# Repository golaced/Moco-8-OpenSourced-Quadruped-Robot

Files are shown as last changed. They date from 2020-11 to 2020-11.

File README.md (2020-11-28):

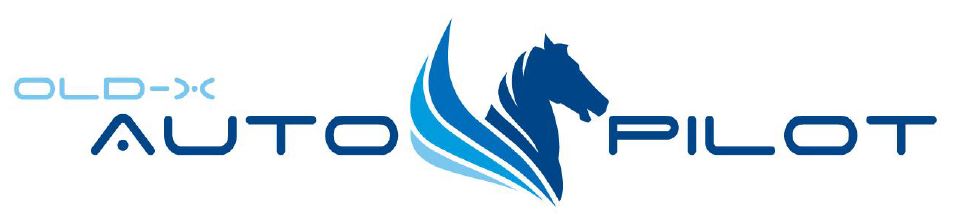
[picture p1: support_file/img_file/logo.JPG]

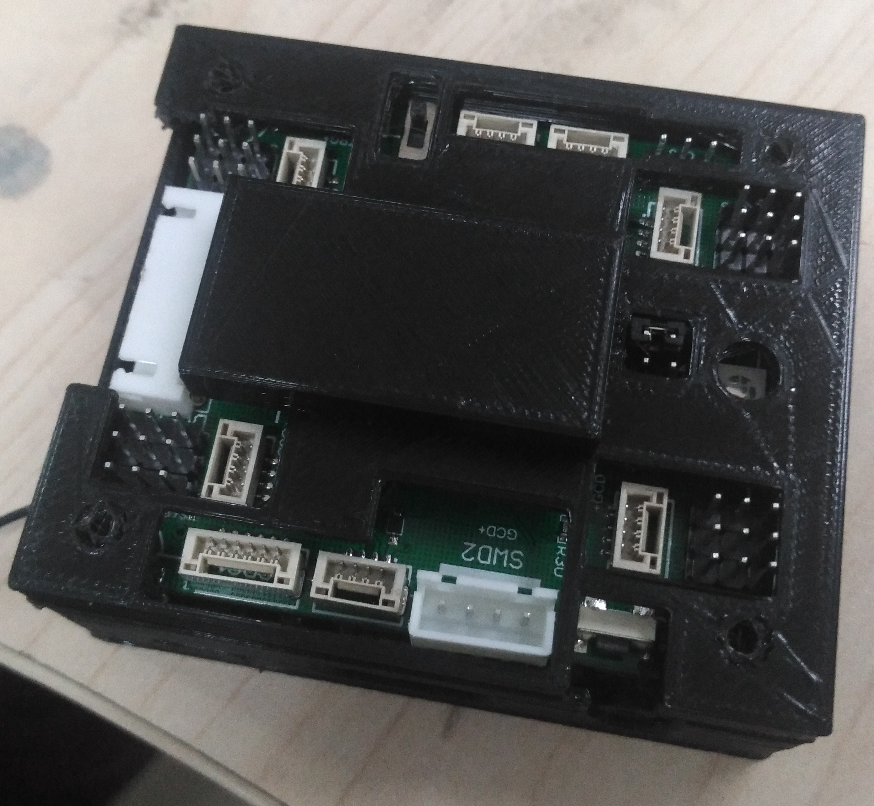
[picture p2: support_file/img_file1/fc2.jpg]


**-项目全开源-**<br>
Moco8项目目前已经全开源，开源PCB加工文件与官方机架，开源VMC原始1.3.5库的完整程序与遥控器程序，同样可以直接从淘宝官网或邮件预定整机（供货周期半个月）<br>

**English Version**：https://github.com/golaced/OLDX-FC_QUADRUPED_QUADROTOR/tree/golaced-patch-1-en <br>

全开源8自由度四足机器人  欢迎Star（原始资料：https://github.com/golaced/OLDX-FC_QUADRUPED_QUADROTOR）<br>
  ____OLDX-MocoMoco四足机器人（OLDX-MocoMoco Quadruped）是目前国内首个真正意义上的开源足式机器人二次开发平台，团队已经开发了一套完整的免费开源
  项目OLDX-FC，随着近年来波士顿动力公司不断推出的足式机器人引起了国内外许多爱好者的关注，也出现了许多电子发烧友自己开发的足式机器人，但
  不同于四轴飞行器仅采用无刷电机和机架就能进行开发，而足式机器人本身结构复杂特别是伺服驱动部分可以独立作为一个学科进行研究，因此造成了
  虽然有许多不错的足式机器人项目但是由于项目成本或者编程语言不为国内环境所熟悉的原因而阻碍了它们的推广或开源。团队4年前就开始研发的六
  足机器人具有丰富的机器人，通过将其与所开发的飞控项目二次结合推出了MocoMoco四足机器人开发平台，囊括机器人结构、步态算法和SLAM无人驾驶
  等多个足式机器人核心技术内容。项目遵循GPL协议，能对DEMO内相关源码进行修改和二次开发。<br><br>

**相关资料** <br>
组装资料教程：https://github.com/golaced/OLDX-FC_QUADRUPED_QUADROTOR<br>
机器人测试视频更新地址：https://www.bilibili.com/video/av46405055 <br>
为方便程序单独下载目前各版本固件从这下载：https://github.com/golaced/MocoMoco_Software<br>
机器人校准视频教程：https://www.bilibili.com/video/av51603154<br>
树莓派镜像和图像程序：https://github.com/golaced/OLDX_VISUAL_FOR_PI<br>
<br>

官方机架taobao链接：https://item.taobao.com/item.htm?spm=a1z10.1-c.w4004-15110596499.22.6b86242c3mvjW9&id=589551490320
<br>
**-如果该项目对您有帮助请 Star 我们的项目-**<br>
**-如果您愿意分享对该项目的优化和改进请联系golaced@163.com或加入我们的QQ群567423074，加速开源项目的进度-**<br>

# 捐赠与项目后续开发计划
____团队计划后期推出5kg~10kg级的足式机器人开发底盘，支持RPlidar激光雷达导航进行SLAM算法验证，能以相同的价格替代目前市面上同类的四轮小车平台如Autolabor等。
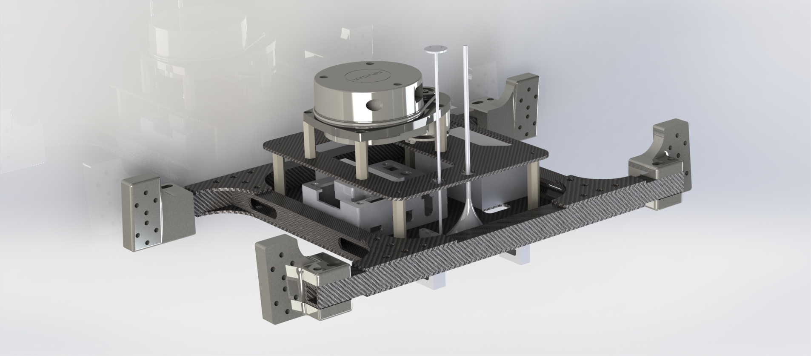
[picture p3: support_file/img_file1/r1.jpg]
 
____如果您觉得该项目对您有帮助，也为了更好的项目推进和软硬件更新，如果愿意请通过微信捐赠该项目！
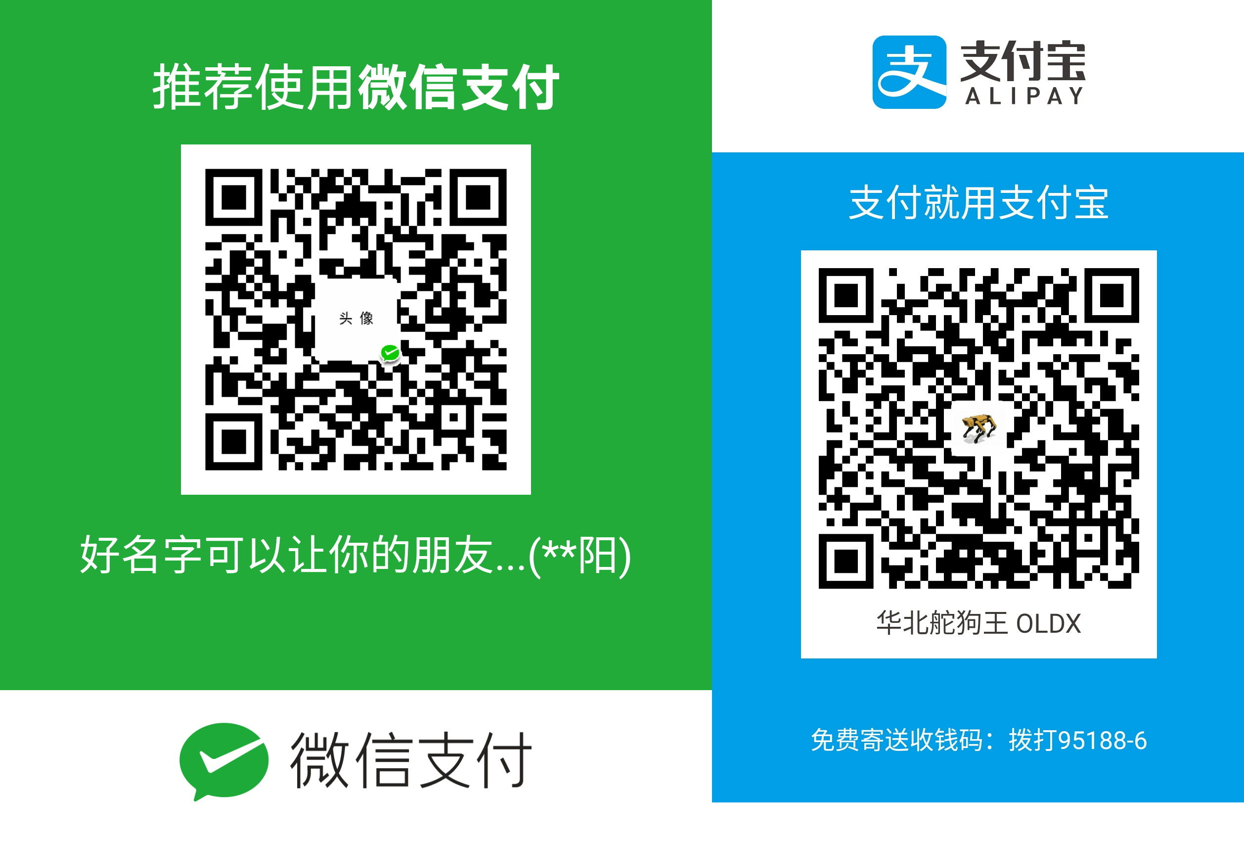
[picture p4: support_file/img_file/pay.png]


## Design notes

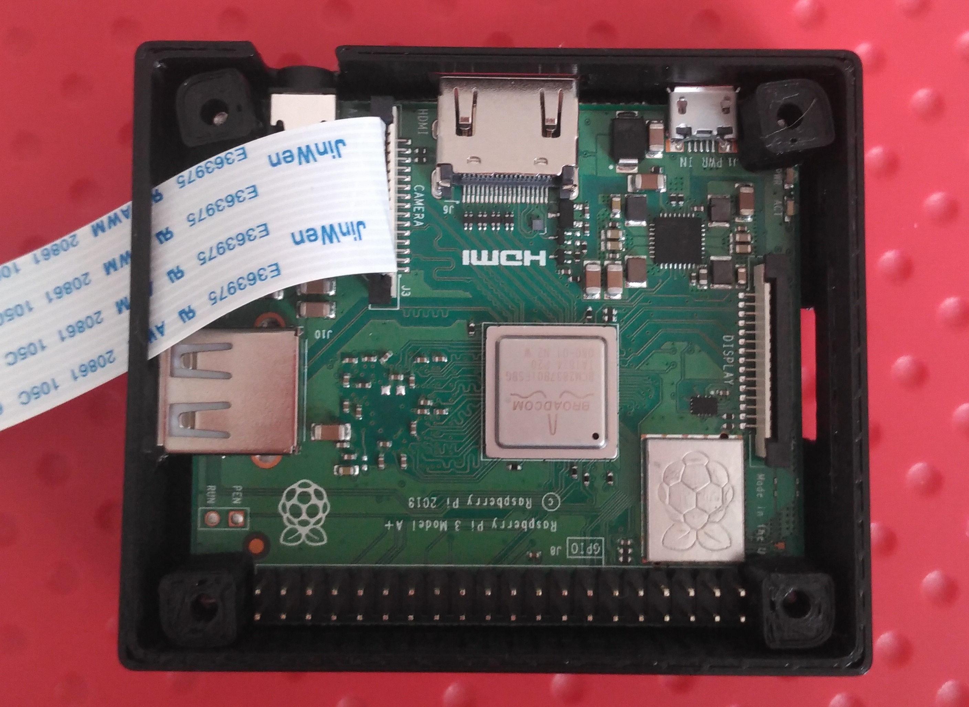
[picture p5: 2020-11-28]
support_file/img_file1/pi1.jpg

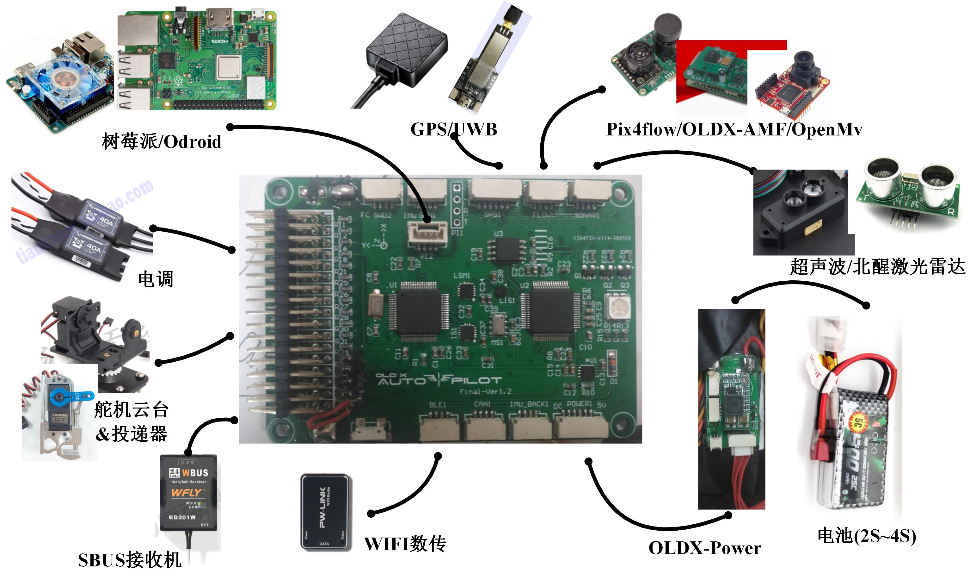
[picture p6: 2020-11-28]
support_file/img_file/line.jpg

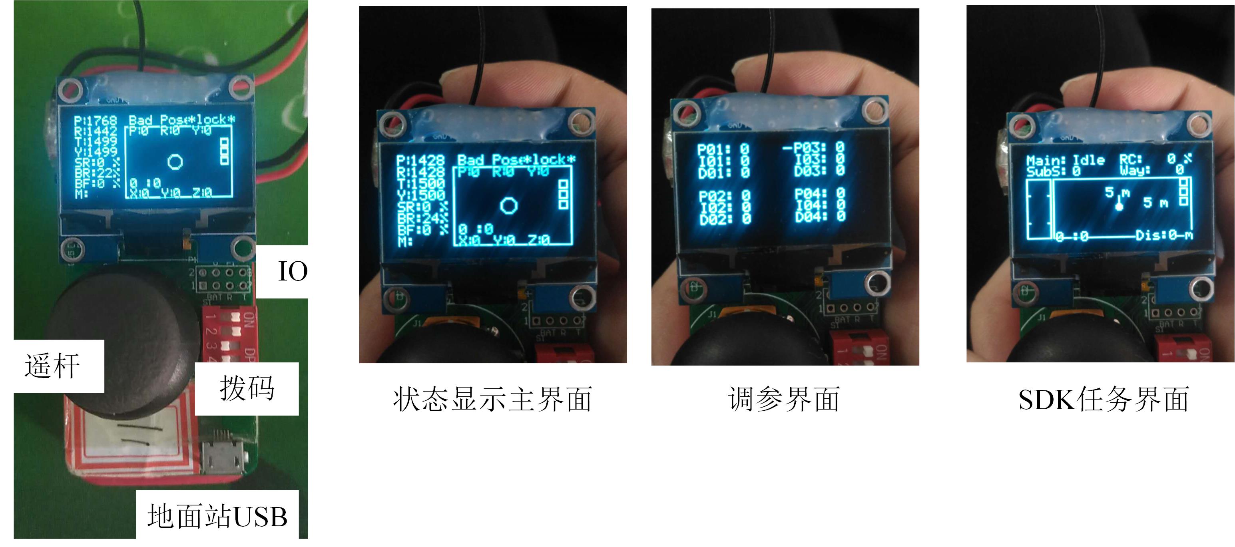
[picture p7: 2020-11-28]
support_file/img_file/remote.jpg

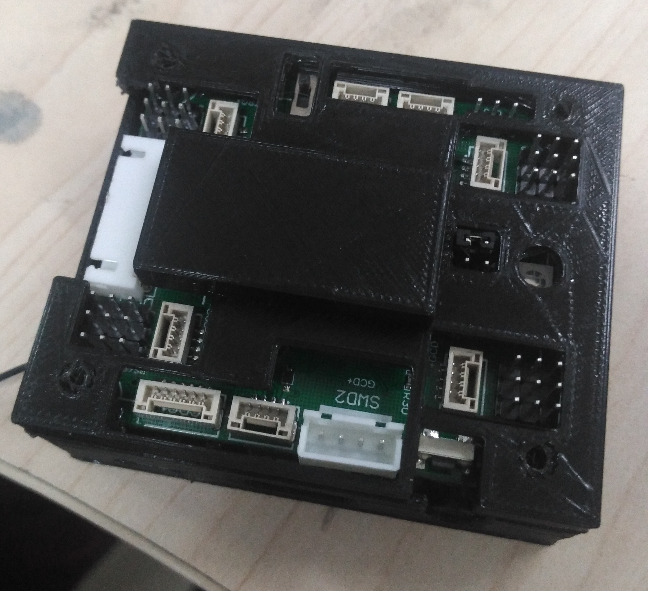
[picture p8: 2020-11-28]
support_file/img_file1/pi3.jpg

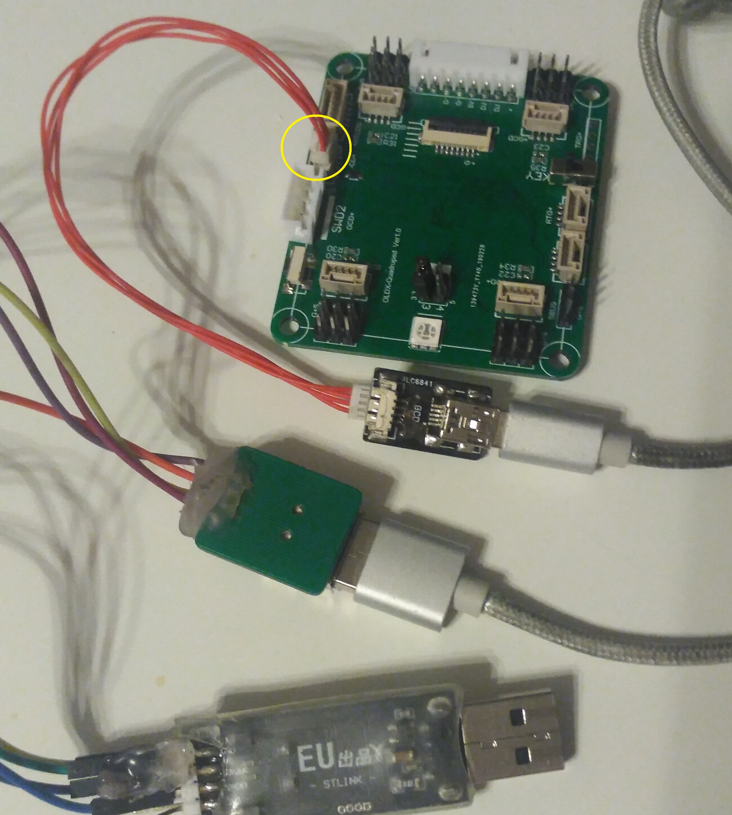
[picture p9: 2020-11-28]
support_file/img_file1/download.jpg

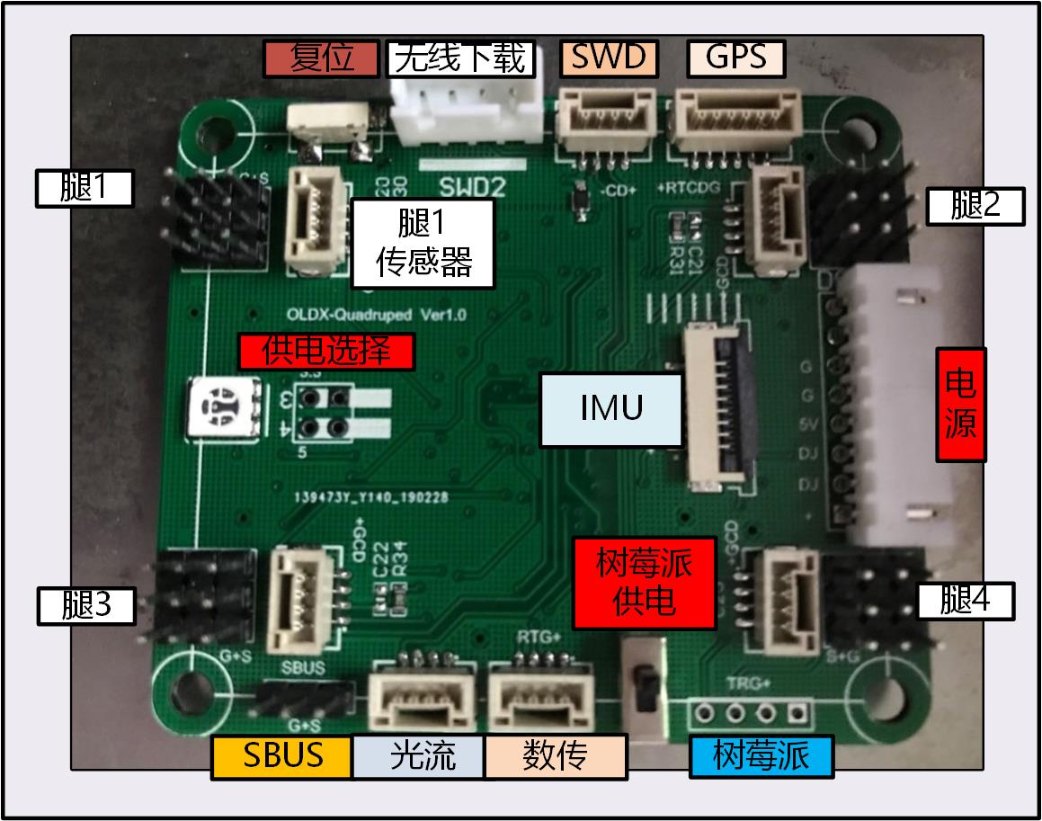
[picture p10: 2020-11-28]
support_file/img_file1/fc.jpg

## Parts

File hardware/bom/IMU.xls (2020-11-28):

Comment | Description | Designator | Footprint | LibRef | Quantity
0.1UF | Capacitor | C1 | C 0402 | CAP | 1
0.1UF | Capacitor | C2, C4, C6 | C0603 | CAP | 3
100nF | Capacitor | C3 | C0603 | CAP | 1
4.7uf | Capacitor | C5 | C0603 | CAP | 1
LIS3MDL | 磁力计 | LIS1 | LIS3MDL | LIS3MDL | 1 | 可选
LSM6DS33 | 加速度计 | LSM1 | LSM6DS33 | LSM6DS33 | 1
Header 8 | 8P 下接 抽屉 | MEMS1 | FH12-8S-1.0SH | Header 8 | 1 | 配1mm 8p软排线 异面 3 cm长
MS5611 | Sensor | MS1 | MS5611 | MS5611 | 1 | 可选

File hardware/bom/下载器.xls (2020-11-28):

Comment | Description | Designator | Footprint | Quantity
0.1UF | Capacitor | C1 | C0603 | 1
1N4148 | 二极管 | D1 | 1n4148-SOD123 | 1
10K | 0603 | R1, R2 | R0603 | 2
MicroUSB口 |  | ST_Link_1 | USB/SM0.8-6H5_M | 1
4P卧贴 | Header, 4-Pin | SWD1 | JST_GH_V4 | 1 | https://item.taobao.com/item.htm?spm=a1z09.2.0.0.MJL2ZN&id=528744124006&_u=o1klsj899edd

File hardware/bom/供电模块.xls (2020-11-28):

Comment | Description | Designator | Footprint | LibRef | Quantity
BAT54WS | 单肖特基二极管 | D1 | SOD-323 | BAT54 | 1
Header 8 | XH2.54 弯端子 | DC1 | HDR1X8 | Header 8 | 1 | 配8P双头线 | 6cm
DET402_1 | 蜂鸣器 | DET1 | BEEP | DET402_1 | 1
DCDC1 | 2.54排针 | DJ1, FC1 | DCDC1 | DCDC1 | 2
S8050 | 8050/BCW846/BCW847 | Q1, Q2 | SOT-23R | NPN | 2
1K | 0603 | R1, R4 | R0603 | Res2 | 2
10K | 0603 | R2 | R0603 | Res2 | 2
NC | 0603 | R3, R5 | R0805 | Res2 | 1
FC1 | 降压模块5V | 控制器供电 |  |  | 1 | https://item.taobao.com/item.htm?spm=a1z09.2.0.0.15212e8dszODOn&id=572382517694&_u=k1klsj89d0b4
DJ1 | 降压模块6V | 舵机供电 |  |  | 1 | https://item.taobao.com/item.htm?spm=a1z09.2.0.0.15212e8dszODOn&id=572382517694&_u=k1klsj89d0b4

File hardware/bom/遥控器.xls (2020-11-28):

Comment | Description | Designator | Footprint | Quantity
AS1364-BTDT-33 | 3.3稳压 | *U1 | TDFN-8 | 1
TP4059 | 充电芯片 | B1 | SOT23-6S | 1
1UF | 贴片电容 | C1, C3 | C0603 | 2
0.1UF | 贴片电容 | C2, C4, C5, C13, C14, C15, C16, C21, C47 | C0603 | 9
20PF | 贴片电容 | C6, C7 | C0603 | 2
10nf | 贴片电容 | C20, C23 | C0603 | 2
4.7uf | 贴片电容 | C22, C24 | C0603 | 2
22uF | 贴片电容 | C25 | C0603 | 1
10UF | 贴片电容 | C48 | C0603 | 1
BAT54WS | 单肖特基二极管 | D1 | SOD-323 | 1
IN4733 5.1V | 稳压二极管5.1V | D2 | 1n4148-SOD123 | 1
蜂鸣器 | 蜂鸣器 | DET1 | BEEP | 1 | https://item.taobao.com/item.htm?id=557399448031&ns=1&abbucket=8
方向摇杆 | 摇杆 | J1 | 摇杆2 | 1 | https://item.taobao.com/item.htm?id=531096275220&ns=1&abbucket=14 (https://item.taobao.com/item.htm?spm=a230r.1.14.99.30965b5bjNmqxk&id=531096275220&ns=1&abbucket=14)
DS0 | LED 蓝 | LED2 | LED_0603 | 1 | 遥杆需要配帽
MPU9250 | 传感器 | MPU1 | MPU_QFN24_0.4 | 1
Header 3 | 三段侧开关 | P2 | HDR1X3 | 1 | https://item.taobao.com/item.htm?id=526166466029
S8050 | 三极管 | Q1 | SOT-23R | 1
1K | 贴片电阻 | R1, R2, R10, R18, R19, R21, R52, R53 | R0603 | 8
1M | 贴片电阻 | R3 | R0603 | 1
10K | 贴片电阻 | R4, R5, R6, R7, R13, R14, R15, R16, R22 | R0603 | 9
10R | 贴片电阻 | R8, R9 | R0603 | 2
0R | 贴片电阻 | R11, R12 | R0603 | 2
4.7K | 贴片电阻 | R17, R20 | R0603 | 2
SW-DIP4 | 拨码开关 | S1 | DIP-8 | 1
SD | 自弹TF卡座 | SD_OLED1 | TF-MicroSD | 1
Header 4 | 卧贴侧端子 | SWD1 | JST_GH_V4 | 1 | 配2根4p双头线 | https://item.taobao.com/item.htm?spm=a1z09.2.0.0.51752e8dlo9hak&id=528691263571&_u=o1klsj894c50
STM32F103C8 | STM32F103c8 | U1 | LQFP48S | 1
USB-B(Mini) | USB | USB | Micro_USB | 1
8MHZ | 无源晶振 | X1 | PXCL | 1
NRF1 | NRF模组 | NRF1 | NRF | 1 | https://item.taobao.com/item.htm?spm=a1z09.2.0.0.65212e8dLKOq2l&id=45719116718&_u=31klsj89072b
OLED | OLED屏幕 | OLED | OLED | 1 | https://detail.tmall.com/item.htm?id=41844085048&spm=a1z09.2.0.0.51752e8dlo9hak&_u=o1klsj895f3e
供电端子(母) |  | https://item.taobao.com/item.htm?spm=a1z09.2.0.0.51752e8dlo9hak&id=39955787073&_u=o1klsj89d67d
G黑线

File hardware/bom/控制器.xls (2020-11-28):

Comment | Description | Designator | Footprint | Quantity
AS1364-BTDT-33 | 降压模块 | *U1 | TDFN-8 | 1
0.1UF | 贴片电容 | C1, C9, C13, C15, C16, C17, C18 | C 0402 | 7
1UF | 贴片电容 | C2 | C 0402 | 1
2.2UF | 贴片电容 | C3, C4 | C0603 | 2
10NF | 贴片电容 | C5 | C 0402 | 1
20PF | 贴片电容 | C6, C7 | C 0402 | 2
4.7uf | 贴片电容 | C10, C12 | C0603 | 2
10nf | 贴片电容 | C11 | C0603 | 1
100uF | 贴片电容 | C19 | C0603 | 1
NC | 贴片电容 | C20, C21, C22, C23 | C0603 | 4
R0 | 单肖特基二极管 | D4 | SOD-323 | 1
SWD2 | 2.54 XH端子 4P 立贴 | SWD2 | SWD2 | 1
Header 8 | 2.54 XH端子 卧贴 | DC | HDR1X8 | 1
Header 4 | GH1.25端子 立贴 | FLOW, IIC1, IIC2, IIC3, IIC4, RADIO, SWD1 | JST_GH_V4 | 7
Header 6 | GH1.25端子 立贴 | GPS1 | JST_GH_V6 | 1 | https://item.taobao.com/item.htm?spm=a1z09.2.0.0.70a52e8drw8IxJ&id=528744124006&_u=l1klsj89de6f
MSK-12D19 | 立三档开关 | KEY | HDR1X3 | 1
5050 RGB | 三色LED | LEDRGB1 | 5050RGB | 1
Header 8 | 1mm软线 翻盖 下接 | MEMS | FH12-8S-1.0SH | 1 | 配30mm异面排线 | 配天线https://item.taobao.com/item.htm?spm=a1z09.2.0.0.16032e8daiTpOp&id=524223974321&_u=k1klsj898d21
NRF模组 | NRF模组 | NRF1 | NRF | 1 | https://item.taobao.com/item.htm?spm=a1z09.2.0.0.65212e8dLKOq2l&id=45719116718&_u=31klsj89072b
Header 3 | 2.54排针 | P1, P2, P3, P5, P6, P7, P8, P9, P10, P11, P12, P13, P14 | HDR1X3 | 13 | 向下焊接
Header 4 | 2.54排针母座 | PI1 | HDR1X4 | 1
S8050 | 8050/BCW846/BCW847 | Q2, Q3, Q4, Q5 | SOT-23R | 4
10K | 贴片电阻 | R1, R4, R5, R6, R33 | R 0402 | 5
1K | 贴片电阻 | R7, R11, R12, R30, R31, R34, R35 | R0603 | 7
560R | 贴片电阻 | R8, R10, R13, R17, R18, R19, R25, R26, R27, R28, R29, R32, R36 | R 0402 | 13
10K | 贴片电阻 | R9 | R0603 | 1
100R | 贴片电阻 | R14, R15, R16 | R 0402 | 3
1K | 贴片电阻 | R20, R21, R22 | R 0402 | 3
Header 2X2 | 2.54排针 | SEL | HDR2X2 | 1 | 配跳线帽
SW-PB1 | 侧贴按键 | SW1 | KEY_SAD | 1
STM32F405RGT6 | 单片机 | U1 | LQFP64_M | 1
W25X16 | W25X16;SST25VF016;MX25L1605 | U2 | W25Q32FVZPIG | 1
8MHZ | 无源晶振 | X1 | PXCL | 1
 | 图中LED焊接错误 缺口应在箭头处

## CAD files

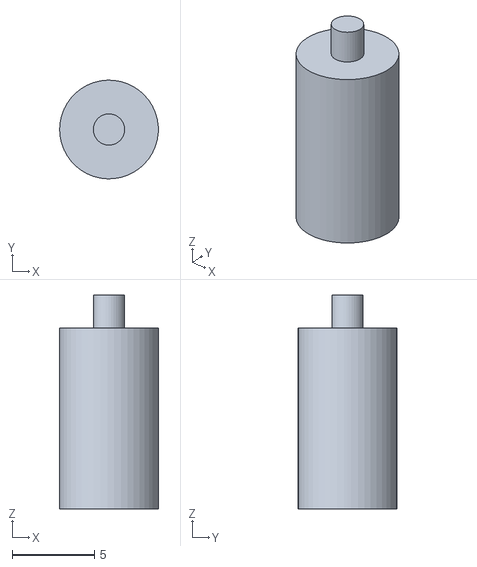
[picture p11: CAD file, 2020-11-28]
hardware/3D print/树莓派支撑_新.STL
6.00 x 6.00 x 13.0

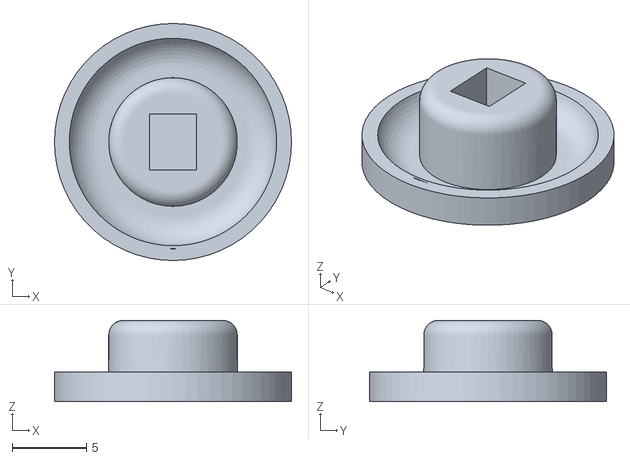
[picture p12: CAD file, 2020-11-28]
quadruped/3D打印测试机架/足底带传感器1.STL
16.0 x 16.0 x 5.50

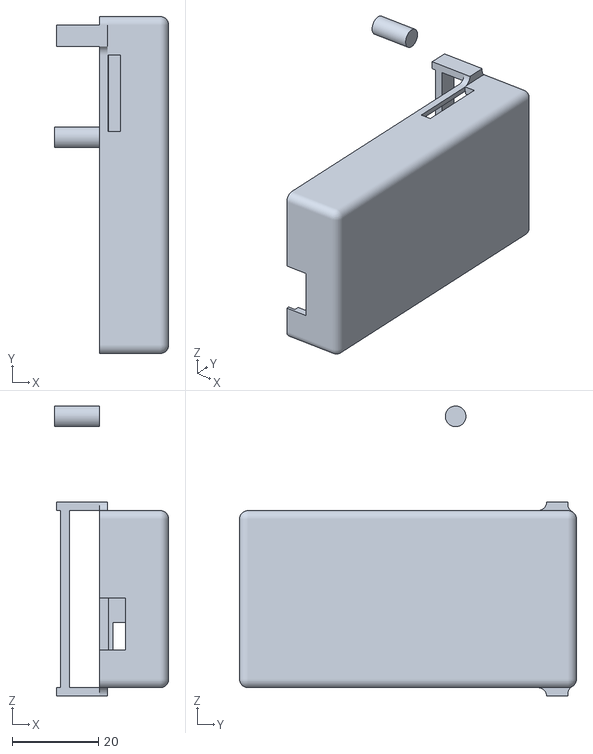
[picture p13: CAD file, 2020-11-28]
hardware/3D print/遥控器外壳.STL
26.5 x 78.0 x 67.1

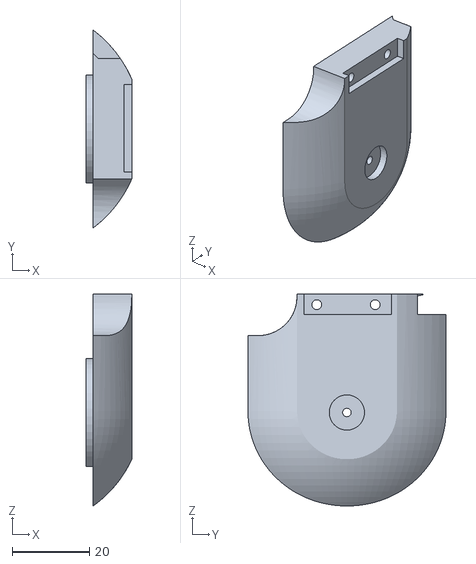
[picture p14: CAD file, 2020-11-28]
quadruped/3D打印测试机架/两轴云台2.STL
11.8 x 51.2 x 54.8

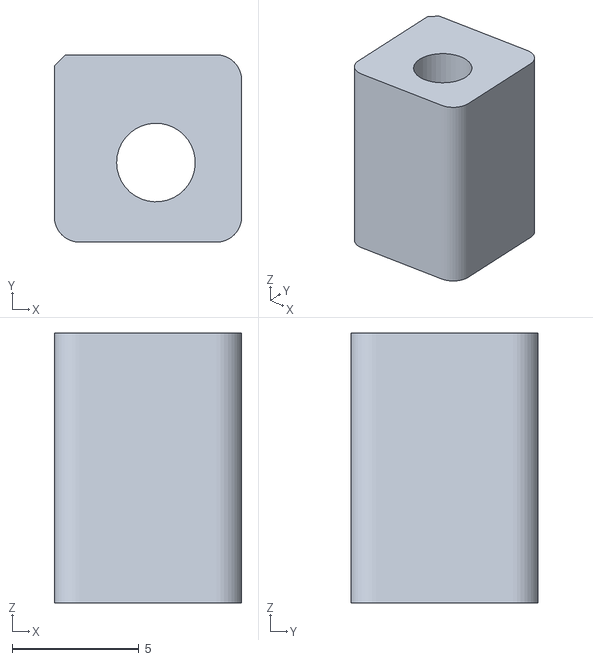
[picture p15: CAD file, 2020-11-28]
hardware/3D print/树莓派支撑.STL
7.39 x 7.39 x 10.6

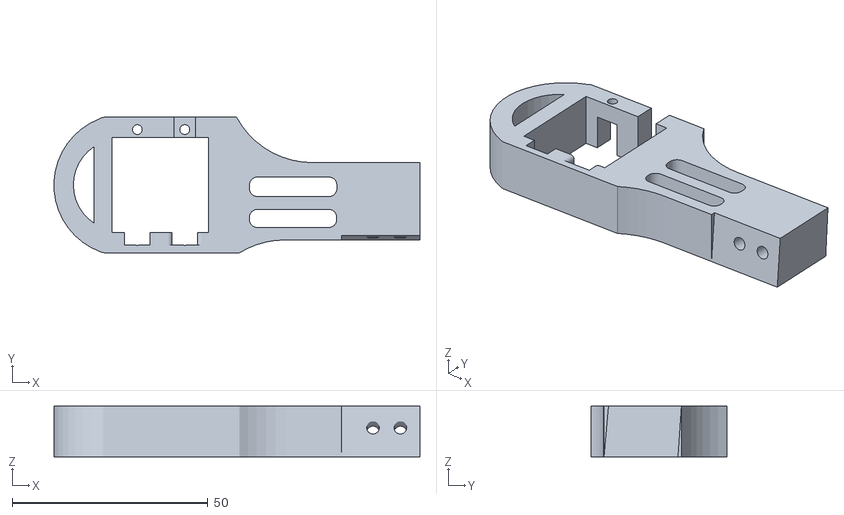
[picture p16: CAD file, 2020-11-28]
quadruped/3D打印测试机架/机臂.STL
93.4 x 34.6 x 13.0

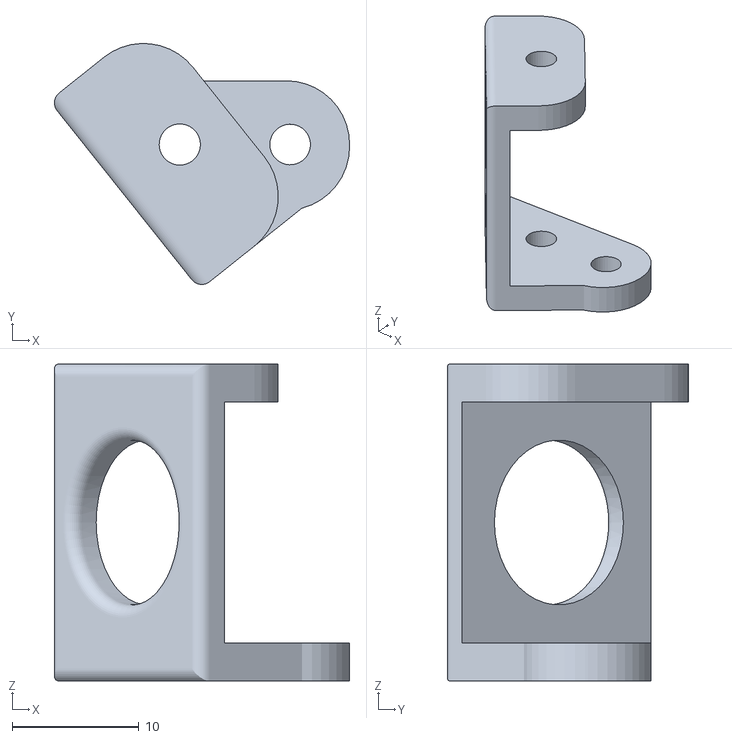
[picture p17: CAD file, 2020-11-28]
quadruped/3D打印测试机架/足底带传感器2(需镜像打印).STL
23.3 x 19.0 x 25.0

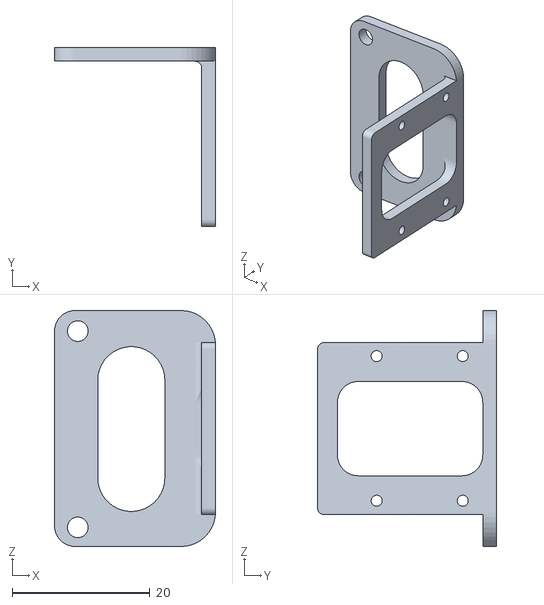
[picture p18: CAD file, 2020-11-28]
quadruped/3D打印测试机架/相机支撑1.STL
23.4 x 26.0 x 34.3

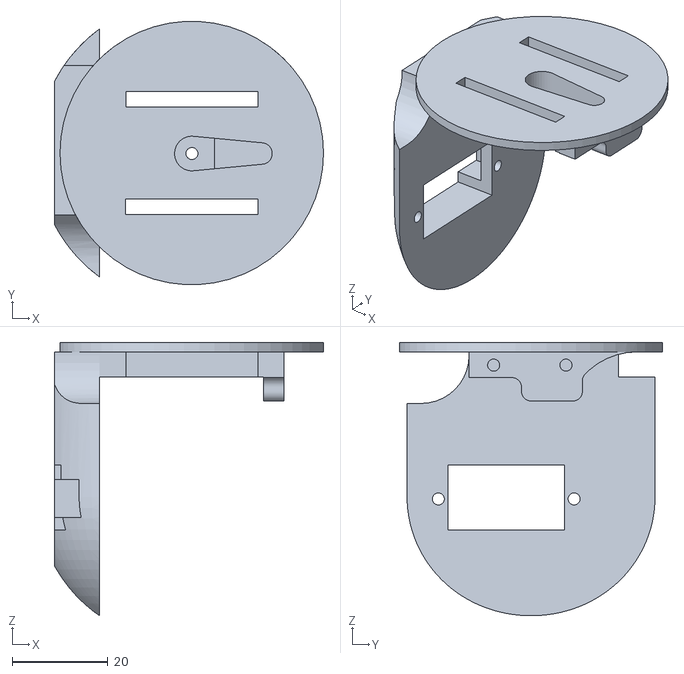
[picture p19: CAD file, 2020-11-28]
quadruped/3D打印测试机架/两轴云台3.STL
56.1 x 54.8 x 57.0

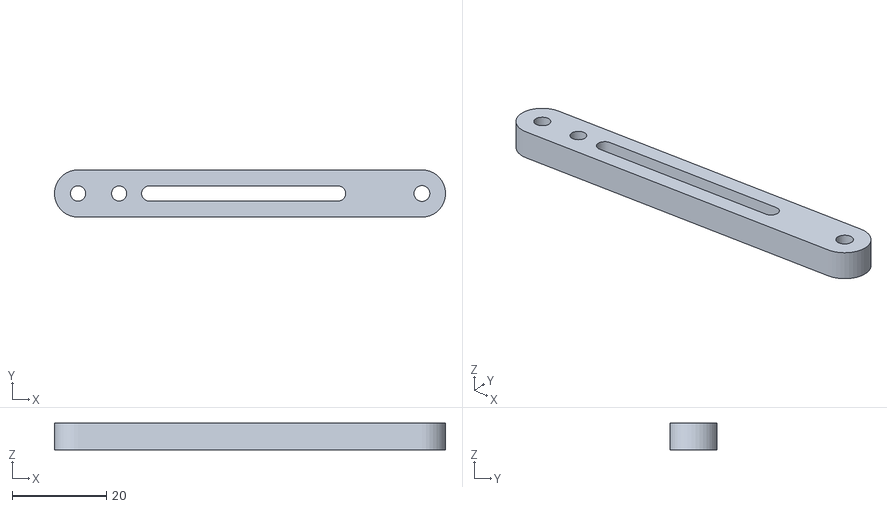
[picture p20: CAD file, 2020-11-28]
quadruped/3D打印测试机架/腿关节.STL
83.0 x 10.1 x 5.70

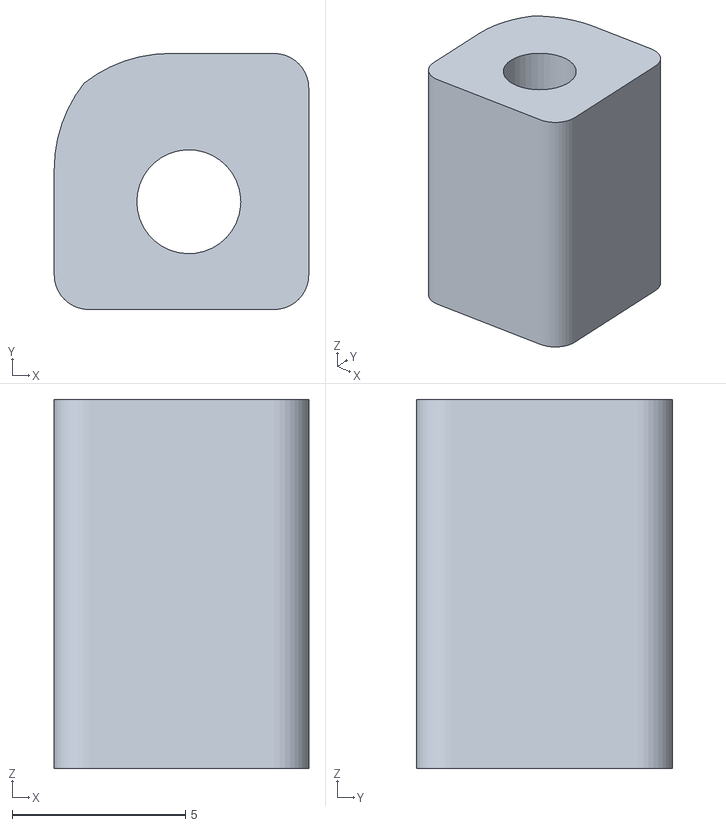
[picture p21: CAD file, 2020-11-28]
quadruped/3D打印测试机架/控制器外壳支撑.STL
7.35 x 7.39 x 10.6

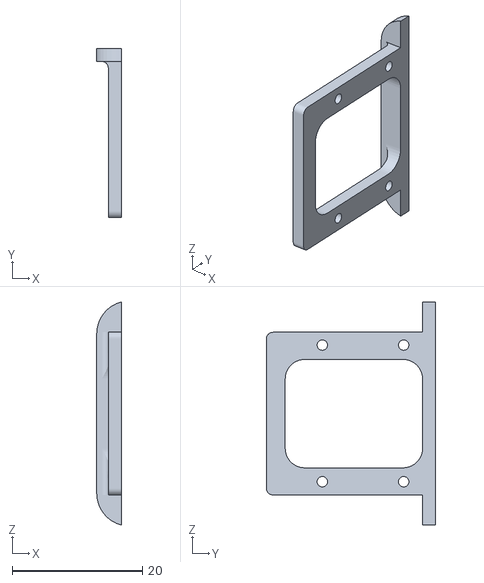
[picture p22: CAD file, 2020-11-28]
quadruped/3D打印测试机架/两轴云台5.STL
3.78 x 26.0 x 34.3

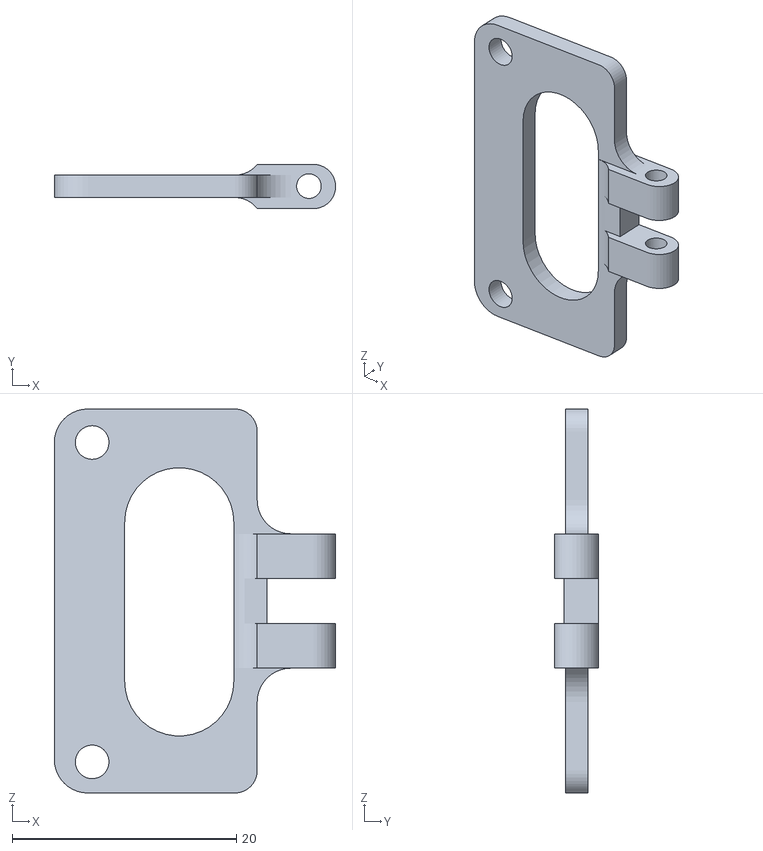
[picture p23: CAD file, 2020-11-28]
quadruped/3D打印测试机架/相机支撑可调 2.STL
25.1 x 3.96 x 34.3

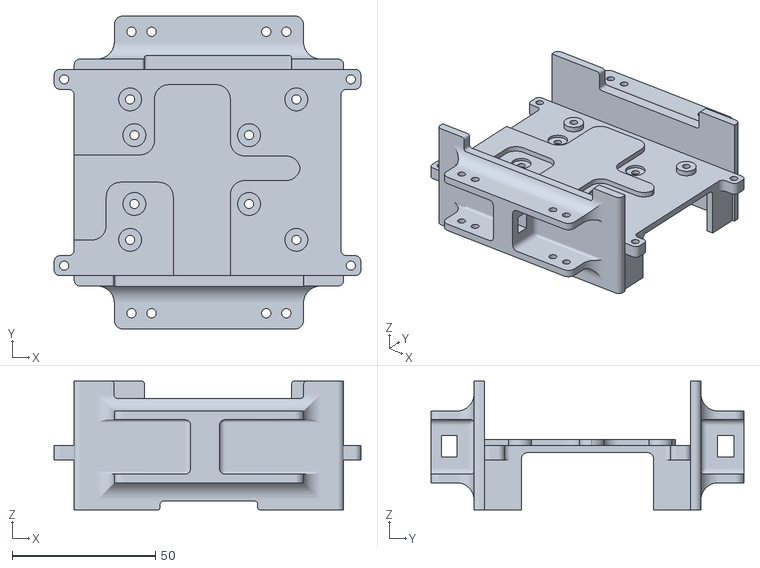
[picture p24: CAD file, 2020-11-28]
quadruped/3D打印测试机架/中心体.STL
107.0 x 109.2 x 45.0

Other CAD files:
quadruped/3D打印测试机架/树莓派相机支撑.STL
quadruped/3D打印测试机架/两轴云台1.STL
quadruped/3D打印测试机架/相机支撑可调1.STL
quadruped/3D打印测试机架/两轴云台4.STL

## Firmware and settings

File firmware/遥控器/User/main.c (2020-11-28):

#include "head.h"
#include "table.h"
#include "spi.h"
#include "nrf.h"
#include "adc.h"
#include "key.h"
#include "mpu9250.h"
#include "FLASH.h"
#include "imu.h"
#include "mymath.h"
#include "math.h"
#include "rc_mine.h"
#include "beep.h"
#include "gui_basic.h"
#include "hw_config.h"
#include "data_transfer.h"
#define USE_AS_MONITER 0
MODULE module;
u8 CHANNAL=44;
float time_fly[5]={0,0,0,0,2.68};
int moniter_sel=0;
int sub_sel[3]={0};
int ts[4];
void OLED_TASK(float dt)//状态界面0
{
	 static int cx,cy;
	 char temp[10][20]={'\0'};
   //GUI_RectangleFill(42,1,123,55,0);
   GUI_RectangleFill(1,1,123,55,0);
   GUI_Rectangle(42,1,123,55,1);
 
   if(plane.module.gps)
		GUI_RectangleFill(115,40,120,45,1);
   else
		GUI_Rectangle(115,40,120,45,1); 
	 
	  if(plane.module.flow)
		GUI_RectangleFill(115,38,120,33,1);
   else
		GUI_Rectangle(115,38,120,33,1); 
	 
	  if(plane.module.vision)
		GUI_RectangleFill(115,31,120,26,1);
   else
		GUI_Rectangle(115,31,120,26,1); 
   #if USE_AS_MONITER
   if(DEBUG[6]!=0&&DEBUG[7]!=0){
   cx=LIMIT(80+(DEBUG[6]-120)*0.35,42+3,123-3);
   cy=LIMIT(28+(DEBUG[7]-160)*0.168,1+3,55-3);
	 GUI_CircleFill(cx,cy,2,1);	 
	 }
	 else
	 GUI_CircleFill(cx,cy,2,0);	 
   #else
   cx=LIMIT(80+(Rc_Get.ROL-1500)*0.1,42+3,123-3);
   cy=LIMIT(28+(Rc_Get.PIT-1500)*0.1,1+3,55-3);
	 GUI_CircleFill(cx,cy,3,1);
   #endif
   GUI_Circle(80,28,5,1);   
   //
   OLED_Refresh_Gram(); 
   delay_us(100);
   //
   OLED_P6x8Str(3,0,"P:");
   my_itoa(Rc_Get.PIT,temp[0]);
	 OLED_P6x8Str(4*3,0,temp[0]);

   OLED_P6x8Str(3,1,"R:");
   my_itoa(Rc_Get.ROL,temp[1]);
	 OLED_P6x8Str(4*3,1,temp[1]);

   OLED_P6x8Str(3,2,"T:");
   my_itoa(Rc_Get.THROTTLE,temp[2]);
	 OLED_P6x8Str(4*3,2,temp[2]);
    delay_us(100);
   OLED_P6x8Str(3,3,"Y:");
   my_itoa(Rc_Get.YA,temp[3]);
	 OLED_P6x8Str(4*3,3,temp[3]);
   //GPS
	 switch(plane.pos_sensor_state)
	 {
	 case 1://flow	 
   OLED_P6x8Str(45,0,"Opt:");
   my_itoa(plane.gps_sv,temp[0]);
	 OLED_P6x8Str(45+5*5,0,temp[0]);
	 break;
	 case 2://qr
	 OLED_P6x8Str(45,0,"QR :");
   my_itoa(plane.gps_sv,temp[0]);
	 OLED_P6x8Str(45+5*5,0,temp[0]);
	 break;
	 case 3://gps	 
   OLED_P6x8Str(45,0,"GPS:");
   my_itoa(plane.gps_sv,temp[0]);
	 OLED_P6x8Str(45+5*5,0,temp[0]);
	 break;
	 default:
	 OLED_P6x8Str(45,0,"Bad Pose");
	 break;
	 
	 }
	   delay_us(100);
  //lock
   if(!plane.lock)
   OLED_P6x8Str(90,0,"*lock*");
   else
	 OLED_P6x8Str(90,0,"*fly!*");
   //SSR
	   delay_us(100);
   OLED_P6x8Str(3,4,"SR:");
   my_itoa(plane.rssi,temp[3]);
	 OLED_P6x8Str(4*5,4,temp[3]);
   OLED_P6x8Str(4*(5+3),4,"%");
   //BAT_RC
	   delay_us(100);
   OLED_P6x8Str(3,5,"BR:");
   my_itoa(adc_rc.bat_percent,temp[4]);
	 OLED_P6x8Str(4*5,5,temp[4]);
   OLED_P6x8Str(4*(5+3),5,"%");
	   delay_us(100);
   //BAT_FLY
   OLED_P6x8Str(3,6,"BF:");
   my_itoa(plane.bat,temp[5]);
	 OLED_P6x8Str(4*5,6,temp[5]);
	 OLED_P6x8Str(4*(5+3),6,"%");
	   delay_us(100);
	 //MODE
   OLED_P6x8Str(3,7,"M:");
   if(plane.mode==1)
		 OLED_P6x8Str(4*3,7,"Munl ");
	 else if(plane.mode==2)
		 OLED_P6x8Str(4*3,7,"Alt B");
	 else if(plane.mode==4)
		 OLED_P6x8Str(4*3,7,"Alt S");
	 else if(plane.mode==3||plane.mode==5)
		 OLED_P6x8Str(4*3,7,"Pos  ");
	   
	 else if(pos_mode==2)
		 OLED_P6x8Str(4*3,7,"Smart");
	 
	 //att
	  OLED_P6x8Str(45,1,"P:");
	  my_itoa(plane.att[1],temp[6]);
	  OLED_P6x8Str(45+3*3,1,temp[6]);
	 
	  OLED_P6x8Str(45+3*8,1,"R:");
	  my_itoa(plane.att[0],temp[7]);
	  OLED_P6x8Str(45+3*8+3*3,1,temp[7]);
	 
	  OLED_P6x8Str(45+3*8*2,1,"Y:");
	  my_itoa(plane.att[2],temp[8]);
	  OLED_P6x8Str(45+3*8*2+3*3,1,temp[8]);
	 
	  OLED_P6x8Str(45,7,"X:");
	  my_itoa(plane.pos[0],temp[6]);
	  OLED_P6x8Str(45+3*3,7,temp[6]);
	 
	  OLED_P6x8Str(45+3*8,7,"Y:");
	  my_itoa(plane.pos[1],temp[6]);
	  OLED_P6x8Str(45+3*8+3*3,7,temp[6]);
		
		OLED_P6x8Str(45+3*8*2,7,"Z:");
	  my_itoa(plane.pos[2],temp[6]);
	  OLED_P6x8Str(45+3*8*2+3*3,7,temp[6]);
		
		//fly time
	  my_itoa(time_fly[0],temp[6]);
	  OLED_P6x8Str(45,6,temp[6]);
		OLED_P6x8Str(45+3*3+3,6,":");
		
	  my_itoa(time_fly[1],temp[6]);
	  OLED_P6x8Str(45+3*3+3*3,6,temp[6]);
}

float set[10]=0;
void OLED_TASK_SUB_SEL(float dt)
{
	 static int cx,cy;
   cx=sub_sel[0]*66+set[1];
   cy=sub_sel[1]*1+set[3];
	 if(sub_sel[2])
	 OLED_P6x8Str(cx,cy,"*");	 
	 else
	 OLED_P6x8Str(cx,cy,"-");
}

void OLED_TASK_PID1(float dt)//参数界面1
{
	 static int cx,cy;
	 char temp[10][40]={'\0'};
   OLED_Fill(0x00);
   OLED_P6x8Str(3+4,0,"P01:");
   my_itoa(plane.PID_RX[0][0],temp[0]);
	 OLED_P6x8Str(36,0,temp[0]);
   OLED_P6x8Str(3+4,1,"I01:");
   my_itoa(plane.PID_RX[0][1],temp[1]);
	 OLED_P6x8Str(36,1,temp[1]);
   OLED_P6x8Str(3+4,2,"D01:");
   my_itoa(plane.PID_RX[0][2],temp[2]);
	 OLED_P6x8Str(36,2,temp[2]);


   OLED_P6x8Str(3+4,4,"P02:");
   my_itoa(plane.PID_RX[1][0],temp[0]);
	 OLED_P6x8Str(36,4,temp[0]);
   OLED_P6x8Str(3+4,5,"I02:");
   my_itoa(plane.PID_RX[1][1],temp[1]);
	 OLED_P6x8Str(36,5,temp[1]);
   OLED_P6x8Str(3+4,6,"D02:");
   my_itoa(plane.PID_RX[1][2],temp[2]);
	 OLED_P6x8Str(36,6,temp[2]);
	 
	 OLED_P6x8Str(3+4+66,0,"P03:");
   my_itoa(plane.PID_RX[2][0],temp[0]);
	 OLED_P6x8Str(36+66,0,temp[0]);
   OLED_P6x8Str(3+4+66,1,"I03:");
   my_itoa(plane.PID_RX[2][1],temp[1]);
	 OLED_P6x8Str(36+66,1,temp[1]);
   OLED_P6x8Str(3+4+66,2,"D03:");
   my_itoa(plane.PID_RX[2][2],temp[2]);
	 OLED_P6x8Str(36+66,2,temp[2]);
	 
	 OLED_P6x8Str(3+4+66,4,"P04:");
   my_itoa(plane.PID_RX[3][0],temp[0]);
	 OLED_P6x8Str(36+66,4,temp[0]);
   OLED_P6x8Str(3+4+66,5,"I04:");
   my_itoa(plane.PID_RX[3][1],temp[1]);
	 OLED_P6x8Str(36+66,5,temp[1]);
   OLED_P6x8Str(3+4+66,6,"D04:");
   my_itoa(plane.PID_RX[3][2],temp[2]);
	 OLED_P6x8Str(36+66,6,temp[2]);
}

void OLED_TASK_PID2(float dt)//参数界面1
{
	 static int cx,cy;
	 char sel=0;
	 char temp[10][40]={'\0'};
   OLED_Fill(0x00);
   sel=4;
   OLED_P6x8Str(3+4,0,"P05:");
   my_itoa(plane.PID_RX[sel][0],temp[0]);
	 OLED_P6x8Str(36,0,temp[0]);
   OLED_P6x8Str(3+4,1,"I05:");
   my_itoa(plane.PID_RX[sel][1],temp[1]);
	 OLED_P6x8Str(36,1,temp[1]);
   OLED_P6x8Str(3+4,2,"D05:");
   my_itoa(plane.PID_RX[sel][2],temp[2]);
	 OLED_P6x8Str(36,2,temp[2]);

   sel=5;
   OLED_P6x8Str(3+4,4,"P06:");
   my_itoa(plane.PID_RX[sel][0],temp[0]);
	 OLED_P6x8Str(36,4,temp[0]);
   OLED_P6x8Str(3+4,5,"I06:");
   my_itoa(plane.PID_RX[sel][1],temp[1]);
	 OLED_P6x8Str(36,5,temp[1]);
   OLED_P6x8Str(3+4,6,"D06:");
   my_itoa(plane.PID_RX[sel][2],temp[2]);
	 OLED_P6x8Str(36,6,temp[2]);
	 
	 sel=6;
	 OLED_P6x8Str(3+4+66,0,"P07:");
   my_itoa(plane.PID_RX[sel][0],temp[0]);
	 OLED_P6x8Str(36+66,0,temp[0]);
   OLED_P6x8Str(3+4+66,1,"I07:");
   my_itoa(plane.PID_RX[sel][1],temp[1]);
	 OLED_P6x8Str(36+66,1,temp[1]);
   OLED_P6x8Str(3+4+66,2,"D07:");
   my_itoa(plane.PID_RX[sel][2],temp[2]);
	 OLED_P6x8Str(36+66,2,temp[2]);
	 
	 sel=7;
	 OLED_P6x8Str(3+4+66,4,"P08:");
   my_itoa(plane.PID_RX[sel][0],temp[0]);
	 OLED_P6x8Str(36+66,4,temp[0]);
   OLED_P6x8Str(3+4+66,5,"I08:");
   my_itoa(plane.PID_RX[sel][1],temp[1]);
	 OLED_P6x8Str(36+66,5,temp[1]);
   OLED_P6x8Str(3+4+66,6,"D08:");
   my_itoa(plane.PID_RX[sel][2],temp[2]);
	 OLED_P6x8Str(36+66,6,temp[2]);
}


void OLED_TASK_PID3(float dt)//参数界面1
{
	 static int cx,cy;
	 char sel=0;
	 char temp[10][40]={'\0'};
   OLED_Fill(0x00);
   sel=8;
   OLED_P6x8Str(3+4,0,"P09:");
   my_itoa(plane.PID_RX[sel][0],temp[0]);
	 OLED_P6x8Str(36,0,temp[0]);
   OLED_P6x8Str(3+4,1,"I09:");
   my_itoa(plane.PID_RX[sel][1],temp[1]);
	 OLED_P6x8Str(36,1,temp[1]);
   OLED_P6x8Str(3+4,2,"D09:");
   my_itoa(plane.PID_RX[sel][2],temp[2]);
	 OLED_P6x8Str(36,2,temp[2]);

   sel=9;
   OLED_P6x8Str(3+4,4,"P10:");
   my_itoa(plane.PID_RX[sel][0],temp[0]);
	 OLED_P6x8Str(36,4,temp[0]);
   OLED_P6x8Str(3+4,5,"I10:");
   my_itoa(plane.PID_RX[sel][1],temp[1]);
	 OLED_P6x8Str(36,5,temp[1]);
   OLED_P6x8Str(3+4,6,"D10:");
   my_itoa(plane.PID_RX[sel][2],temp[2]);
	 OLED_P6x8Str(36,6,temp[2]);
	 
	 sel=10;
	 OLED_P6x8Str(3+4+66,0,"P11:");
   my_itoa(plane.PID_RX[sel][0],temp[0]);
	 OLED_P6x8Str(36+66,0,temp[0]);
   OLED_P6x8Str(3+4+66,1,"I11:");
   my_itoa(plane.PID_RX[sel][1],temp[1]);
	 OLED_P6x8Str(36+66,1,temp[1]);
   OLED_P6x8Str(3+4+66,2,"D11:");
   my_itoa(plane.PID_RX[sel][2],temp[2]);
	 OLED_P6x8Str(36+66,2,temp[2]);
	 
	 sel=11;
	 OLED_P6x8Str(3+4+66,4,"P12:");
   my_itoa(plane.PID_RX[sel][0],temp[0]);
	 OLED_P6x8Str(36+66,4,temp[0]);
   OLED_P6x8Str(3+4+66,5,"I12:");
   my_itoa(plane.PID_RX[sel][1],temp[1]);
	 OLED_P6x8Str(36+66,5,temp[1]);
   OLED_P6x8Str(3+4+66,6,"D12:");
   my_itoa(plane.PID_RX[sel][2],temp[2]);
	 OLED_P6x8Str(36+66,6,temp[2]);
}


void OLED_TASK_PID4(float dt)//参数界面1
{
	 static int cx,cy;
	 char sel=0;
	 char temp[10][40]={'\0'};
   OLED_Fill(0x00);
   sel=12;
   OLED_P6x8Str(3+4,0,"P13:");
   my_itoa(plane.PID_RX[sel][0],temp[0]);
	 OLED_P6x8Str(36,0,temp[0]);
   OLED_P6x8Str(3+4,1,"I13:");
   my_itoa(plane.PID_RX[sel][1],temp[1]);
	 OLED_P6x8Str(36,1,temp[1]);
   OLED_P6x8Str(3+4,2,"D13:");
   my_itoa(plane.PID_RX[sel][2],temp[2]);
	 OLED_P6x8Str(36,2,temp[2]);

   sel=13;
   OLED_P6x8Str(3+4,4,"P14:");
   my_itoa(plane.PID_RX[sel][0],temp[0]);
	 OLED_P6x8Str(36,4,temp[0]);
   OLED_P6x8Str(3+4,5,"I14:");
   my_itoa(plane.PID_RX[sel][1],temp[1]);
	 OLED_P6x8Str(36,5,temp[1]);
   OLED_P6x8Str(3+4,6,"D14:");
   my_itoa(plane.PID_RX[sel][2],temp[2]);
	 OLED_P6x8Str(36,6,temp[2]);
	 
	 sel=14;
	 OLED_P6x8Str(3+4+66,0,"P15:");
   my_itoa(plane.PID_RX[sel][0],temp[0]);
	 OLED_P6x8Str(36+66,0,temp[0]);
   OLED_P6x8Str(3+4+66,1,"I15:");
   my_itoa(plane.PID_RX[sel][1],temp[1]);
	 OLED_P6x8Str(36+66,1,temp[1]);
   OLED_P6x8Str(3+4+66,2,"D15:");
   my_itoa(plane.PID_RX[sel][2],temp[2]);
	 OLED_P6x8Str(36+66,2,temp[2]);
	 
	 sel=15;
	 OLED_P6x8Str(3+4+66,4,"P16:");
   my_itoa(plane.PID_RX[sel][0],temp[0]);
	 OLED_P6x8Str(36+66,4,temp[0]);
   OLED_P6x8Str(3+4+66,5,"I16:");
   my_itoa(plane.PID_RX[sel][1],temp[1]);
	 OLED_P6x8Str(36+66,5,temp[1]);
   OLED_P6x8Str(3+4+66,6,"D16:");
   my_itoa(plane.PID_RX[sel][2],temp[2]);
	 OLED_P6x8Str(36+66,6,temp[2]);
}



void OLED_TASK_PID5(float dt)//参数界面1
{
	 static int cx,cy;
	 char sel=0;
	 char temp[10][40]={'\0'};
   OLED_Fill(0x00);
   sel=16;
   OLED_P6x8Str(3+4,0,"P17:");
   my_itoa(plane.PID_RX[sel][0],temp[0]);
	 OLED_P6x8Str(36,0,temp[0]);
   OLED_P6x8Str(3+4,1,"I17:");
   my_itoa(plane.PID_RX[sel][1],temp[1]);
	 OLED_P6x8Str(36,1,temp[1]);
   OLED_P6x8Str(3+4,2,"D17:");
   my_itoa(plane.PID_RX[sel][2],temp[2]);
	 OLED_P6x8Str(36,2,temp[2]);

   sel=17;
   OLED_P6x8Str(3+4,4,"P18:");
   my_itoa(plane.PID_RX[sel][0],temp[0]);
	 OLED_P6x8Str(36,4,temp[0]);
   OLED_P6x8Str(3+4,5,"I18:");
   my_itoa(plane.PID_RX[sel][1],temp[1]);
	 OLED_P6x8Str(36,5,temp[1]);
   OLED_P6x8Str(3+4,6,"D18:");
   my_itoa(plane.PID_RX[sel][2],temp[2]);
	 OLED_P6x8Str(36,6,temp[2]);
	 
// 	 sel=18;
// 	 OLED_P6x8Str(3+3+66,0,"P70:");
//    my_itoa(plane.PID_RX[sel][0],temp[0]);
// 	 OLED_P6x8Str(36+66,0,temp[0]);
//    OLED_P6x8Str(3+3+66,1,"P71:");
//    my_itoa(plane.PID_RX[sel][1],temp[1]);
// 	 OLED_P6x8Str(36+66,1,temp[1]);
//    OLED_P6x8Str(3+3+66,2,"P72:");
//    my_itoa(plane.PID_RX[sel][2],temp[2]);
// 	 OLED_P6x8Str(36+66,2,temp[2]);
// 	 
	 sel=19;
// 	 OLED_P6x8Str(3+3+66,4,"P80:");
//    my_itoa(plane.PID_RX[sel][0],temp[0]);
// 	 OLED_P6x8Str(36+66,4,temp[0]);
//    OLED_P6x8Str(3+3+66,5,"P81:");
//    my_itoa(plane.PID_RX[sel][1],temp[1]);
// 	 OLED_P6x8Str(36+66,5,temp[1]);
   OLED_P6x8Str(3+3+66,6,"CH :");
   my_itoa(plane.PID_RX[sel][2],temp[2]);
	 OLED_P6x8Str(36+66,6,temp[2]);
}
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
int main(void)
{	u8 i,j;
	static u16 cnt_flag[10];
	char temp[10][20]={'\0'};
  static u8 moniter_reg,fly_reg;
  static int cnt_get_data;
	u8 pid_sel[2],page,sub_page;

//------------------------------------//
	delay_init(72);		//延时初始化
	TIM3_Config();
	Cycle_Time_Init();
	OLED_Init();
	USART_init();	
	Adc_Init();
	SPI1_Init();		
	Parameter_Init();
	Nrf24l01_Init(MODEL_TX2,CHANNAL);// 伪双工  主接收
	Nrf24l01_Check();
	Mpu9250_Init();
  keyInit(); 
	OLED_Fill(0x00);OLED_P6x8Str(3,0,"By Golaced-BIT ");OLED_P8x16Str(43,3,"Welcome!");
	if(module.nrf)
	OLED_P6x8Str(3,7,"Nrf2.4G OK!");
	if(module.acc)
	OLED_P6x8Str(3,6,"Mpu9250 OK!");
	
  OLED_P6x8Str(3,5,"Channle:");
  my_itoa(CHANNAL,temp[0]);
  OLED_P6x8Str(50,5,temp[0]);
	delay_ms(20000);
	OLED_Fill(0x00);
	Beep_Init(0,72-1);
	Play_Music_Direct(START_BEEP);
	usb_vcp_init();
	delay_ms(1000);
	Time4ON();
	__enable_irq();
	while(1){
     if(rst_screen){rst_screen=0;
		 OLED_Fill(0x00);}
		 if(flag_ms[2]==1)
		 {
      flag_ms[2]=0;
			dt[0] = Get_Cycle_T(0)/1000000.0f;	
      if(dt[0]>0.005)
				dt[0]=0.005;
			else if(dt[0]<0.0015)
				dt[0]=0.0015;
			getFlyDataADCValue();
			MPU9250_ReadValue();
			MPU6050_Data_Prepare(dt[0]);
		 } 
		 
     if(flag_ms[5]==1)
		 {
      flag_ms[5]=0;
			dt[1] = Get_Cycle_T(1)/1000000.0f;	  
			if(dt[1]>0.01)
				dt[1]=0.01;
			else if(dt[1]<0.0025)
				dt[1]=0.0025;
			//IMUupdate(0.5f *dt[1],mpu6050_fc.Gyro_deg.x, mpu6050_fc.Gyro_deg.y, mpu6050_fc.Gyro_deg.z, mpu6050_fc.Acc.x, mpu6050_fc.Acc.y, mpu6050_fc.Acc.z,&Rol_fc,&Pit_fc,&Yaw_fc); 
			madgwick_update_new( mpu6050_fc.Acc.x, mpu6050_fc.Acc.y, mpu6050_fc.Acc.z,mpu6050_fc.Gyro_deg.x/57.3, mpu6050_fc.Gyro_deg.y/57.3, mpu6050_fc.Gyro_deg.z/57.3,20,20,20, &Rol_fc,&Pit_fc,&Yaw_fc,dt[1]); 
			adc_rc.pitch=LIMIT(-my_deathzoom1(Pit_fc-off_att[0],0)*1.345*1.234,-45,45)/45.*500+1500;
			adc_rc.roll=LIMIT(my_deathzoom1(Rol_fc-off_att[1],0)*1.345,-45,45)/45.*500+1500; 
			Rc_Get.PIT=LIMIT(adc_rc.pitch,1000,2000);
			Rc_Get.ROL=LIMIT(adc_rc.roll,1000,2000);
			Rc_Get.YA=LIMIT(adc_rc.yaw,1000,2000);
			Rc_Get.THROTTLE=LIMIT(adc_rc.thrust,1000,2000);
			if(key_o[4]&&moniter_sel==0){
           key_sel_down++;
        }
				if(key_sel_down>2/0.005){
					  key_sel_down=0;
					  sub_sel[2]=!sub_sel[2];
					  off_att[0]=Pit_fc;
					  off_att[1]=Rol_fc;
					  WRITE_PARM();
					  Play_Music_Direct(RC_RESET_BEEP);				  
				}
       ANO_DT_Data_Exchange(); 	
		 } 
  
		 if(flag_ms[10]==1)
		 {
			dt[2] = Get_Cycle_T(2)/1000000.0f;	
      Nrf_Check_Event();
			RC_Send_Task();	
			 		 
      flag_ms[10]=0;
		 }
		 
		  if(flag_ms[20]==1)
		 {
			dt[3] = Get_Cycle_T(3)/1000000.0f;	   
      flag_ms[20]=0;
     
		 }
		 
		 if(flag_ms[25]==1)
		 {
			dt[4] = Get_Cycle_T(4)/1000000.0f;	   
      flag_ms[25]=0;
			
		 }

		 if(flag_ms[50]==1)
		 {
			dt[5] = Get_Cycle_T(5)/1000000.0f;	   
      flag_ms[50]=0;
			if(fly_reg==0&&plane.lock)
			{time_fly[3]=1;time_fly[0]=time_fly[1]=time_fly[2]=0;}
			if(fly_reg==1&&plane.lock==0)
				time_fly[3]=0;
			fly_reg=plane.lock;
			if(time_fly[3])
				time_fly[2]+=dt[5]*time_fly[4];
			if(time_fly[2]>1){
				time_fly[1]+=time_fly[2];
			  time_fly[2]-=1;
		  }
			if(time_fly[1]>60){
				time_fly[0]++;time_fly[1]-=60;
			} 
			
			#if USE_AS_MONITER 
			  if(Rc_Get.YA>1800)
				{cnt_flag[0]++;cnt_flag[2]++;}
				else
				{cnt_flag[0]=0;cnt_flag[2]=0;}
				
				if(Rc_Get.YA<1200)
				{cnt_flag[1]++;cnt_flag[3]++;}
				else
				{cnt_flag[1]=0;cnt_flag[3]=0;}
			 
				if(Rc_Get.THROTTLE>1800)
				{cnt_flag[4]++;cnt_flag[6]++;}
				else
				{cnt_flag[4]=0;cnt_flag[6]=0;}
				
				if(Rc_Get.THROTTLE<1200)
				{cnt_flag[5]++;cnt_flag[7]++;}
				else
				{cnt_flag[5]=0;cnt_flag[7]=0;}
				
				if(cnt_flag[1]>1/0.05)
				{cnt_flag[1]=cnt_flag[2]=0;moniter_sel--;}	
				if(cnt_flag[0]>1/0.05)
				{cnt_flag[0]=cnt_flag[3]=0;moniter_sel++;}	
				//---------------------
				if(cnt_flag[2]>0.1/0.05)
				{cnt_flag[1]=cnt_flag[2]=0;if(sub_sel[2]==0)sub_sel[0]--;}	
				if(cnt_flag[3]>0.1/0.05)
				{cnt_flag[0]=cnt_flag[3]=0;if(sub_sel[2]==0)sub_sel[0]++;}	
				
				if(key_o[4])
				{cnt_flag[8]++;cnt_flag[9]++;}
				else
				 cnt_flag[8]=cnt_flag[9]=0;
				if(cnt_flag[8]>0.1/0.05){
					  cnt_flag[8]=0;
					  sub_sel[2]=!sub_sel[2];
				}
				if(cnt_flag[9]>1.25/0.05&&moniter_sel!=0){
					  cnt_flag[9]=0;
					  for(i=0;i<18;i++)
					    for(j=0;j<3;j++)
					         plane.PID[i][j]=plane.PID_RX[i][j];
            Play_Music_Direct(UPLOAD_BEEP);
					  send_pid=1;
					  sub_sel[2]=0;
				}
				
				if(cnt_flag[6]>0.1/0.05)
				{cnt_flag[4]=cnt_flag[6]=0;if(sub_sel[2]==0)sub_sel[1]--;if(sub_sel[1]==3)sub_sel[1]=2;}	
				if(cnt_flag[7]>0.1/0.05)
				{cnt_flag[5]=cnt_flag[7]=0;if(sub_sel[2]==0)sub_sel[1]++;if(sub_sel[1]==3)sub_sel[1]=4;}	
				
				if(sub_sel[0]>1)
					sub_sel[0]=0;
				if(sub_sel[0]<0)
					sub_sel[0]=1;
				if(sub_sel[1]>6)
					sub_sel[1]=0;
				if(sub_sel[1]<0)
					sub_sel[1]=6;
				
				if(moniter_sel>6)
					moniter_sel=0;
				if(moniter_sel<0)
					moniter_sel=6;
				
			//change data
			if(sub_sel[1]<3)	
				sub_page=sub_sel[1];
			else
				sub_page=sub_sel[1]-4;
			
			if(sub_sel[0]==0&&sub_sel[1]<3)
				 page=0;
			if(sub_sel[0]==0&&sub_sel[1]>3)
				 page=1;
			if(sub_sel[0]==1&&sub_sel[1]<3)
				 page=2;
			if(sub_sel[0]==1&&sub_sel[1]>3)
				 page=3;
			
			pid_sel[0]=LIMIT((moniter_sel-1)*4+page,0,20);
			pid_sel[1]=LIMIT(sub_page,0,2);
					
			if(sub_sel[2]){	
				plane.PID_RX[pid_sel[0]][pid_sel[1]]+=my_deathzoom1(Rc_Get.THROTTLE-1500,50)*0.01;
				plane.PID_RX[pid_sel[0]][pid_sel[1]]+=my_deathzoom1(Rc_Get.YA-1500,150)*0.2;
				plane.PID_RX[pid_sel[0]][pid_sel[1]]=LIMIT(plane.PID_RX[pid_sel[0]][pid_sel[1]],0,9999);
			}	
			#endif 
			switch(moniter_sel)
      {
       case 0:				
			   OLED_TASK(0.05);  
			 break;
			 case 1:
				 OLED_TASK_PID1(0.05); OLED_TASK_SUB_SEL(0.05);
         if(cnt_get_data++>2.5/0.05)
				  {cnt_get_data=0;plane.read_pid=1;}					 
			 break;
			 case 2:
				 OLED_TASK_PID2(0.05); OLED_TASK_SUB_SEL(0.05);
         if(cnt_get_data++>2.5/0.05)
				  {cnt_get_data=0;plane.read_pid=1;}					 
			 break;	
			case 3:
				OLED_TASK_PID3(0.05); OLED_TASK_SUB_SEL(0.05);
				if(cnt_get_data++>2.5/0.05)
				{cnt_get_data=0;plane.read_pid=1;}					 
			break;	
			case 4:
				OLED_TASK_PID4(0.05); OLED_TASK_SUB_SEL(0.05);
				if(cnt_get_data++>2.5/0.05)
				{cnt_get_data=0;plane.read_pid=1;}					 
			break;	
			case 5:
				OLED_TASK_PID5(0.05); OLED_TASK_SUB_SEL(0.05);
				if(cnt_get_data++>2.5/0.05)
				{cnt_get_data=0;plane.read_pid=1;}					 
			break;
      case 6:
        OLED_TASK_MISSION(0.05);
      break;			
		  }
			if(sub_sel[2]==1)
				cnt_get_data=0;
			if(moniter_reg==0&&moniter_sel!=0)
				plane.read_pid=1;
			if(moniter_reg!=moniter_sel)
				sub_sel[2]=0;
			moniter_reg=moniter_sel;
			BEEP_TASK(0.05); 
			KEY_Scan(0.05);	
		 }
		 
		 
	}
}
/*********************************************END OF FILE**********************/

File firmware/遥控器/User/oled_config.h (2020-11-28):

#ifndef _OLED_CONFIG_H
#define _OLED_CONFIG_H

#include "stm32f10x.h"
#define OLED_GPIO    GPIOC
#define OLED_RCCEN   RCC_APB2Periph_GPIOC
#define OLED_SCL     GPIO_Pin_15      //D0
#define OLED_SDA     GPIO_Pin_3      //D1
#define OLED_RST     GPIO_Pin_4      //RST
#define OLED_DC      GPIO_Pin_5      //DC

#define OLED_CMD  0	//写命令
#define OLED_DATA 1	//写数据

#define OLED_D0_OL		GPIO_ResetBits(GPIOA, OLED_SCL)	//D0 IO口输出低电平
#define OLED_D0_OH		GPIO_SetBits(GPIOA, OLED_SCL)  	//D0 IO口输出高电平

#define OLED_D1_OL		GPIO_ResetBits(GPIOB, OLED_SDA)	//D1 IO口输出低电平
#define OLED_D1_OH		GPIO_SetBits(GPIOB, OLED_SDA) 	//D1 IO口输出高电平

#define OLED_RST_OL		GPIO_ResetBits(GPIOB, OLED_RST)	//RST IO口输出低电平
#define OLED_RST_OH		GPIO_SetBits(GPIOB, OLED_RST) 	//RST IO口输出高电平

#define OLED_DC_OL		GPIO_ResetBits(GPIOB, OLED_DC)	//DC IO口输出低电平
#define OLED_DC_OH		GPIO_SetBits(GPIOB, OLED_DC) 	//DC IO口输出高电平



#define OLED_RST_Clr()  GPIO_ResetBits(GPIOB, OLED_RST) //RST IO口输出低电平
#define OLED_RST_Set()  GPIO_SetBits(GPIOB, OLED_RST) 	//RST IO口输出高电平

#define OLED_RS_Clr()   GPIO_ResetBits(GPIOB, OLED_DC)	//DC IO口输出低电平
#define OLED_RS_Set()   GPIO_SetBits(GPIOB, OLED_DC) 	  //DC IO口输出高电平


#define OLED_SCLK_Clr() GPIO_ResetBits(GPIOA, OLED_SCL)	//D0 IO口输出低电平
#define OLED_SCLK_Set() GPIO_SetBits(GPIOA, OLED_SCL)  	//D0 IO口输出高电平

#define OLED_SDIN_Clr() GPIO_ResetBits(GPIOB, OLED_SDA)	//D1 IO口输出低电平
#define OLED_SDIN_Set() GPIO_SetBits(GPIOB, OLED_SDA) 	//D1 IO口输出高电平

   void setgpio(void);
   void OLED_Init(void);
   void OLED_CLS(void);
   void OLED_4num(unsigned char x,unsigned char y,int number);
   void OLED_3num(unsigned char x,unsigned char y,unsigned char number);
   void OLED_Num(unsigned char x,unsigned char y,unsigned char asc);
   void OLED_P6x8Str(unsigned char x,unsigned char y,unsigned char ch[]);
   void OLED_P8x16Str(unsigned char x,unsigned char y,unsigned char ch[]);
   void OLED_P14x16Str(unsigned char x,unsigned char y,unsigned char ch[]);
  void OLED_Print(unsigned char x, unsigned char y, unsigned char ch[]);
  void OLED_PutPixel(unsigned char x,unsigned char y);
  void OLED_Rectangle(int16_t acc_x,int16_t acc_y);
  void Draw_LQLogo(void);
  void Draw_LibLogo(void);
  void Draw_BMP(unsigned char x0,unsigned char y0,unsigned char x1,unsigned char y1,unsigned char bmp[]); 
  void OLED_Fill(unsigned char dat);
  void Dis_String(unsigned char y, unsigned char x, unsigned char ch[]);
  void Dis_Char(unsigned char y,unsigned char x,unsigned char asc);
  void Dis_Num(unsigned char y, unsigned char x, unsigned int num,unsigned char N);
  void Dis_Float(unsigned char Y,unsigned char X,double real,unsigned char N);
  void Dis_Float2(unsigned char Y,unsigned char X,double real,unsigned char N1,unsigned char N2);
  void OLED_P6x8Num_8bit(unsigned char x,unsigned char y,unsigned char Number); 
  void OLED_Num5(unsigned char x,unsigned char y,unsigned int number);
	void UPDATE_SCREEN(void);
	extern void display_128x64(unsigned char *dp);
	extern void display_128x64_SD(unsigned char *dp);
	extern  unsigned char FIG[];
extern	void OLED_Refresh_Gram(void);


extern void OLED_DrawPoint(u8 x,u8 y,u8 t);

#endif

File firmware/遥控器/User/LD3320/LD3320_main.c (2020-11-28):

#include  <stm32f10x.h>
#include "stm32f10x_conf.h"
#include "LDchip.h"
#include "Reg_RW.h"
#include "LD3320_config.h"


/************************************************************************************
//	nAsrStatus 用来在main主程序中表示程序运行的状态，不是LD3320芯片内部的状态寄存器
//	LD_ASR_NONE:		表示没有在作ASR识别
//	LD_ASR_RUNING：		表示LD3320正在作ASR识别中
//	LD_ASR_FOUNDOK:		表示一次识别流程结束后，有一个识别结果
//	LD_ASR_FOUNDZERO:	表示一次识别流程结束后，没有识别结果
//	LD_ASR_ERROR:		表示一次识别流程中LD3320芯片内部出现不正确的状态
*********************************************************************************/
uint8 nAsrStatus=0;	

void LD3320_Init(void);
uint8 RunASR(void);
void ProcessInt0(void);
void LD3320_EXTI_Cfg(void);
void LD3320_Spi_cfg(void);
void LD3320_GPIO_Cfg(void);
void LED_gpio_cfg(void);

/***********************************************************
* 名    称： LD3320_main(void)
* 功    能： 主函数LD3320程序入口
* 入口参数：  
* 出口参数：
* 说    明：
* 调用方法： 
**********************************************************/ 

void  LD3320_main(void)
{
	uint8 nAsrRes=0;
	LD3320_Init();	  
  PrintCom(TEST_USART," 串口运行中....\r\n"); 
	PrintCom(TEST_USART,"口令：1、流水灯\r\n"); 
	PrintCom(TEST_USART,"2、闪烁\r\n"); 				
	PrintCom(TEST_USART,"3、按键触发\r\n"); 		
	PrintCom(TEST_USART,"4、全灭\r\n"); 			

	nAsrStatus = LD_ASR_NONE;		//	初始状态：没有在作ASR

	while(1)
	{
 	switch(nAsrStatus)
		{
			case LD_ASR_RUNING:
			case LD_ASR_ERROR:		
					break;
			case LD_ASR_NONE:
					nAsrStatus=LD_ASR_RUNING;
					if (RunASR()==0)	//	启动一次ASR识别流程：ASR初始化，ASR添加关键词语，启动ASR运算
					{		
						nAsrStatus = LD_ASR_ERROR;
					}
					break;

			case LD_ASR_FOUNDOK:
					 nAsrRes = LD_GetResult( );	//	一次ASR识别流程结束，去取ASR识别结果										 
						PrintCom(TEST_USART,"\r\n识别码:");			
						USART_SendData(TEST_USART,nAsrRes+0x30); 		
								
					 switch(nAsrRes)		   /*对结果执行相关操作,客户修改*/
						{
							case CODE_LSD:			/*命令“流水灯”*/
								PrintCom(TEST_USART,"“流水灯”命令识别成功\r\n"); 
															 break;
							case CODE_SS:	 /*命令“闪烁”*/
								PrintCom(TEST_USART,"“闪烁”命令识别成功\r\n"); 
															 break;
							case CODE_AJCF:		/*命令“按键触发”*/
					
								PrintCom(TEST_USART,"“按键触发”命令识别成功\r\n"); 
															break;
							case CODE_QM:		/*命令“全灭”*/
					
								PrintCom(TEST_USART,"“全灭”命令识别成功\r\n");
															break;
							default:break;
						}	
						nAsrStatus = LD_ASR_NONE;
					break;
			
			case LD_ASR_FOUNDZERO:
			default:
						nAsrStatus = LD_ASR_NONE;
						break;
			}//switch
	//开发板测试延时部分（用户可删除）		
		Board_text(nAsrRes );
	}// while

}
/***********************************************************
* 名    称：LD3320_Init(void)
* 功    能：模块驱动端口初始配置
* 入口参数：  
* 出口参数：
* 说    明：
* 调用方法： 
**********************************************************/ 
void LD3320_Init(void)
{
	LD3320_GPIO_Cfg();	
	LD3320_EXTI_Cfg();
	LD3320_Spi_cfg();	 
	LED_gpio_cfg();
	LD_reset();
}

/***********************************************************
* 名    称： void Delay_(int i)
* 功    能： 短延时
* 入口参数：  
* 出口参数：
* 说    明：
* 调用方法： 
**********************************************************/ 
void Delay_( int i)
 {     
    while(i--);
 }	
/***********************************************************
* 名    称：	LD3320_delay(unsigned long uldata)
* 功    能：	长延时函数
* 入口参数：  
* 出口参数：
* 说    明：
* 调用方法： 
**********************************************************/ 
void LD3320_delay(unsigned long uldata)
{
	unsigned int j  =  0;
	unsigned int g  =  0;
	for (j=0;j<5;j++)
	{
		for (g=0;g<uldata;g++)
		{
			Delay_(120);
		}
	}
}

/***********************************************************
* 名    称：	RunASR(void)
* 功    能：	运行ASR
* 入口参数：  
* 出口参数：
* 说    明：
* 调用方法： 
**********************************************************/ 
uint8 RunASR(void)
{
	uint8 i=0;
	uint8 asrflag=0;
	for (i=0; i<5; i++)					//	防止由于硬件原因导致LD3320芯片工作不正常，所以一共尝试5次启动ASR识别流程
	{
		LD_AsrStart();						//初始化ASR
		LD3320_delay(100);
		if (LD_AsrAddFixed()==0)	//添加关键词语到LD3320芯片中
		{
			LD_reset();							//	LD3320芯片内部出现不正常，立即重启LD3320芯片
			LD3320_delay(50);				//	并从初始化开始重新ASR识别流程
			continue;
		}
		LD3320_delay(10);
		if (LD_AsrRun() == 0)
		{
			LD_reset();							//	LD3320芯片内部出现不正常，立即重启LD3320芯片
			LD3320_delay(50);				//	并从初始化开始重新ASR识别流程
			continue;
		}
		asrflag=1;
		break;										//	ASR流程启动成功，退出当前for循环。开始等待LD3320送出的中断信号
	}	
	return asrflag;
}

/***********************************************************
* 名    称：LD3320_GPIO_Cfg(void)
* 功    能：初始化需要用到的IO口
* 入口参数：  
* 出口参数：
* 说    明：
* 调用方法： 
**********************************************************/ 
void LD3320_GPIO_Cfg(void)
{	
		GPIO_InitTypeDef GPIO_InitStructure;	
		RCC_APB2PeriphClockCmd(LD3320RST_GPIO_CLK | LD3320CS_GPIO_CLK,ENABLE);
		//LD_CS	/RSET
		GPIO_InitStructure.GPIO_Pin =LD3320CS_PIN;
		GPIO_InitStructure.GPIO_Speed = GPIO_Speed_50MHz;
		GPIO_InitStructure.GPIO_Mode = GPIO_Mode_Out_PP;
		GPIO_Init(LD3320CS_GPIO_PORT,&GPIO_InitStructure);
		GPIO_InitStructure.GPIO_Pin =LD3320RST_PIN;
		GPIO_Init(LD3320RST_GPIO_PORT,&GPIO_InitStructure);

}
/***********************************************************
* 名    称：LD3320_Spi_cfg(void)
* 功    能：配置SPI功能和端口初始化
* 入口参数：  
* 出口参数：
* 说    明：
* 调用方法： 
**********************************************************/ 
void LD3320_Spi_cfg(void)
{
	SPI_InitTypeDef  SPI_InitStructure;
	GPIO_InitTypeDef GPIO_InitStructure;
  //spi端口配置
	RCC_APB2PeriphClockCmd(LD3320SPI_CLK,ENABLE);	   //使能SPI2外设时钟
  RCC_APB2PeriphClockCmd(LD3320WR_GPIO_CLK | LD3320SPIMISO_GPIO_CLK | LD3320SPIMOSI_GPIO_CLK | LD3320SPISCK_GPIO_CLK,ENABLE);
	
	GPIO_InitStructure.GPIO_Pin = LD3320SPIMISO_PIN;
	GPIO_InitStructure.GPIO_Speed = GPIO_Speed_50MHz;
	GPIO_InitStructure.GPIO_Mode = GPIO_Mode_AF_PP;
	GPIO_Init(LD3320SPIMISO_GPIO_PORT,&GPIO_InitStructure);
	
	GPIO_InitStructure.GPIO_Pin = LD3320SPIMOSI_PIN;
	GPIO_Init(LD3320SPIMOSI_GPIO_PORT,&GPIO_InitStructure);

	GPIO_InitStructure.GPIO_Pin = LD3320SPISCK_PIN;
	GPIO_Init(LD3320SPISCK_GPIO_PORT,&GPIO_InitStructure);
	
	GPIO_InitStructure.GPIO_Pin = LD3320WR_PIN;			//WR
	GPIO_InitStructure.GPIO_Speed = GPIO_Speed_50MHz;
	GPIO_InitStructure.GPIO_Mode = GPIO_Mode_Out_PP;
	GPIO_Init(LD3320WR_GPIO_PORT, &GPIO_InitStructure);
	
	LD_CS_H();
	
	SPI_Cmd(LD3320SPI, DISABLE);

	SPI_InitStructure.SPI_Direction = SPI_Direction_2Lines_FullDuplex;   	//全双工
	SPI_InitStructure.SPI_Mode = SPI_Mode_Master;						   						//主模式
	SPI_InitStructure.SPI_DataSize = SPI_DataSize_8b;					   					//8位
	SPI_InitStructure.SPI_CPOL = SPI_CPOL_High;						   							//时钟极性 空闲状态时，SCK保持低电平
	SPI_InitStructure.SPI_CPHA = SPI_CPHA_1Edge;						   						//时钟相位 数据采样从第一个时钟边沿开始
	SPI_InitStructure.SPI_NSS = SPI_NSS_Soft;							   							//软件产生NSS
	SPI_InitStructure.SPI_BaudRatePrescaler = SPI_BaudRatePrescaler_64;   //波特率控制 SYSCLK/128
	SPI_InitStructure.SPI_FirstBit = SPI_FirstBit_MSB;				   					//数据高位在前
	SPI_InitStructure.SPI_CRCPolynomial = 7;							   							//CRC多项式寄存器初始值为7
	SPI_Init(LD3320SPI, &SPI_InitStructure);

	SPI_Cmd(LD3320SPI, ENABLE);

}
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

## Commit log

2020-11-28 开源更新
    [IMU.PcbDoc, IMU.xls, 下载器.xls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]
2020-11-28 更新机架
    [leg1_1.SLDPRT, legend_2.SLDPRT, 中心体支撑.STL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]
